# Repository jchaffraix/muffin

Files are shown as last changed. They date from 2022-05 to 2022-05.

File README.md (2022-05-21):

# muffin

A small mechanical keyboard for learning (and fun).

The goal is to build a small factor to learn how to build the PCB, soldering small components
and writing the firmware.

## Features

* USB-C connector.
* 5 keys, using Cherry MX or Kailh choc switches, including a 2U with a stabilizer.
* 1 rotary encoder.
* ATmega16 based.
* Mostly 805 SMT components.
* Include a programmer connector for ease of prototyping.
* A Muffin logo (because why not!?).

## PCB

The project relies on the [Keebio parts](https://github.com/keebio/Keebio-Parts.pretty) repository for the encoder and switch footprints.

To fetch the dependencies, run:

```
git submodule fetch
```

## Bill Of Materials

| Item | Package | Qty | Reference |
|---|---|-----|---|
| 10uF Capacitor | SMT 805 | 1 | |
| 1uF Capacitor | SMT 805 | 1 | |
| .1uF Capacitor | SMT 805 | 4 | |
| 22pF Capacitor | SMT 805 | 2 | |
| Diode | SMT 805 | 5 | Rated 5V |
| 5.5V Zener Diode | SMT 805 | 1 |  |
| LED Red | SMT 805 | 1 | |
| LED Blue | SMT 805 | 1 | |
| LED Green | SMT 805 | 1 | |
| 10k resistor | SMT 805 | 1 | |
| 5.1k resistor | SMT 805 | 2 | |
| 330 resistor | SMT 805 | 4 | |
| 22 resistor | SMT 805 | 2 | |
| USB ESD protection | SOT-143 | 1 |  Used D1213A-02SR-7|
| USB C receptable (female) | | 1 | Used HRO-TYPE-C-31-M-12 |
| AVR-ISP-6 connector | | 1 | |
| RotaryEncoder Switch | | 1 | Used Alps EC11 |
| Cherry or Kailh choc Switches | | 5 | |
| Switch stabilizer for 2U | | 1 | |
| ATmega16U4-M | QFN-44 | 1 | ATmega32U4 should work too|
| 16MHz crystal | | 1 | Used 3155-16M20P2/49US-ND |
| Reset switch | | 1 | Used MJTP1117 |
| Optional programming Switch | SMT 254 | 1 | Used 2223-DS04-254-2-01BK-SMT-ND |

Note: The crystal and the 2pF capacitors can be omitted if you use the internal clock (which requires programming some bits on the ATmega16).

## Compiling and flashing

Coming soon.

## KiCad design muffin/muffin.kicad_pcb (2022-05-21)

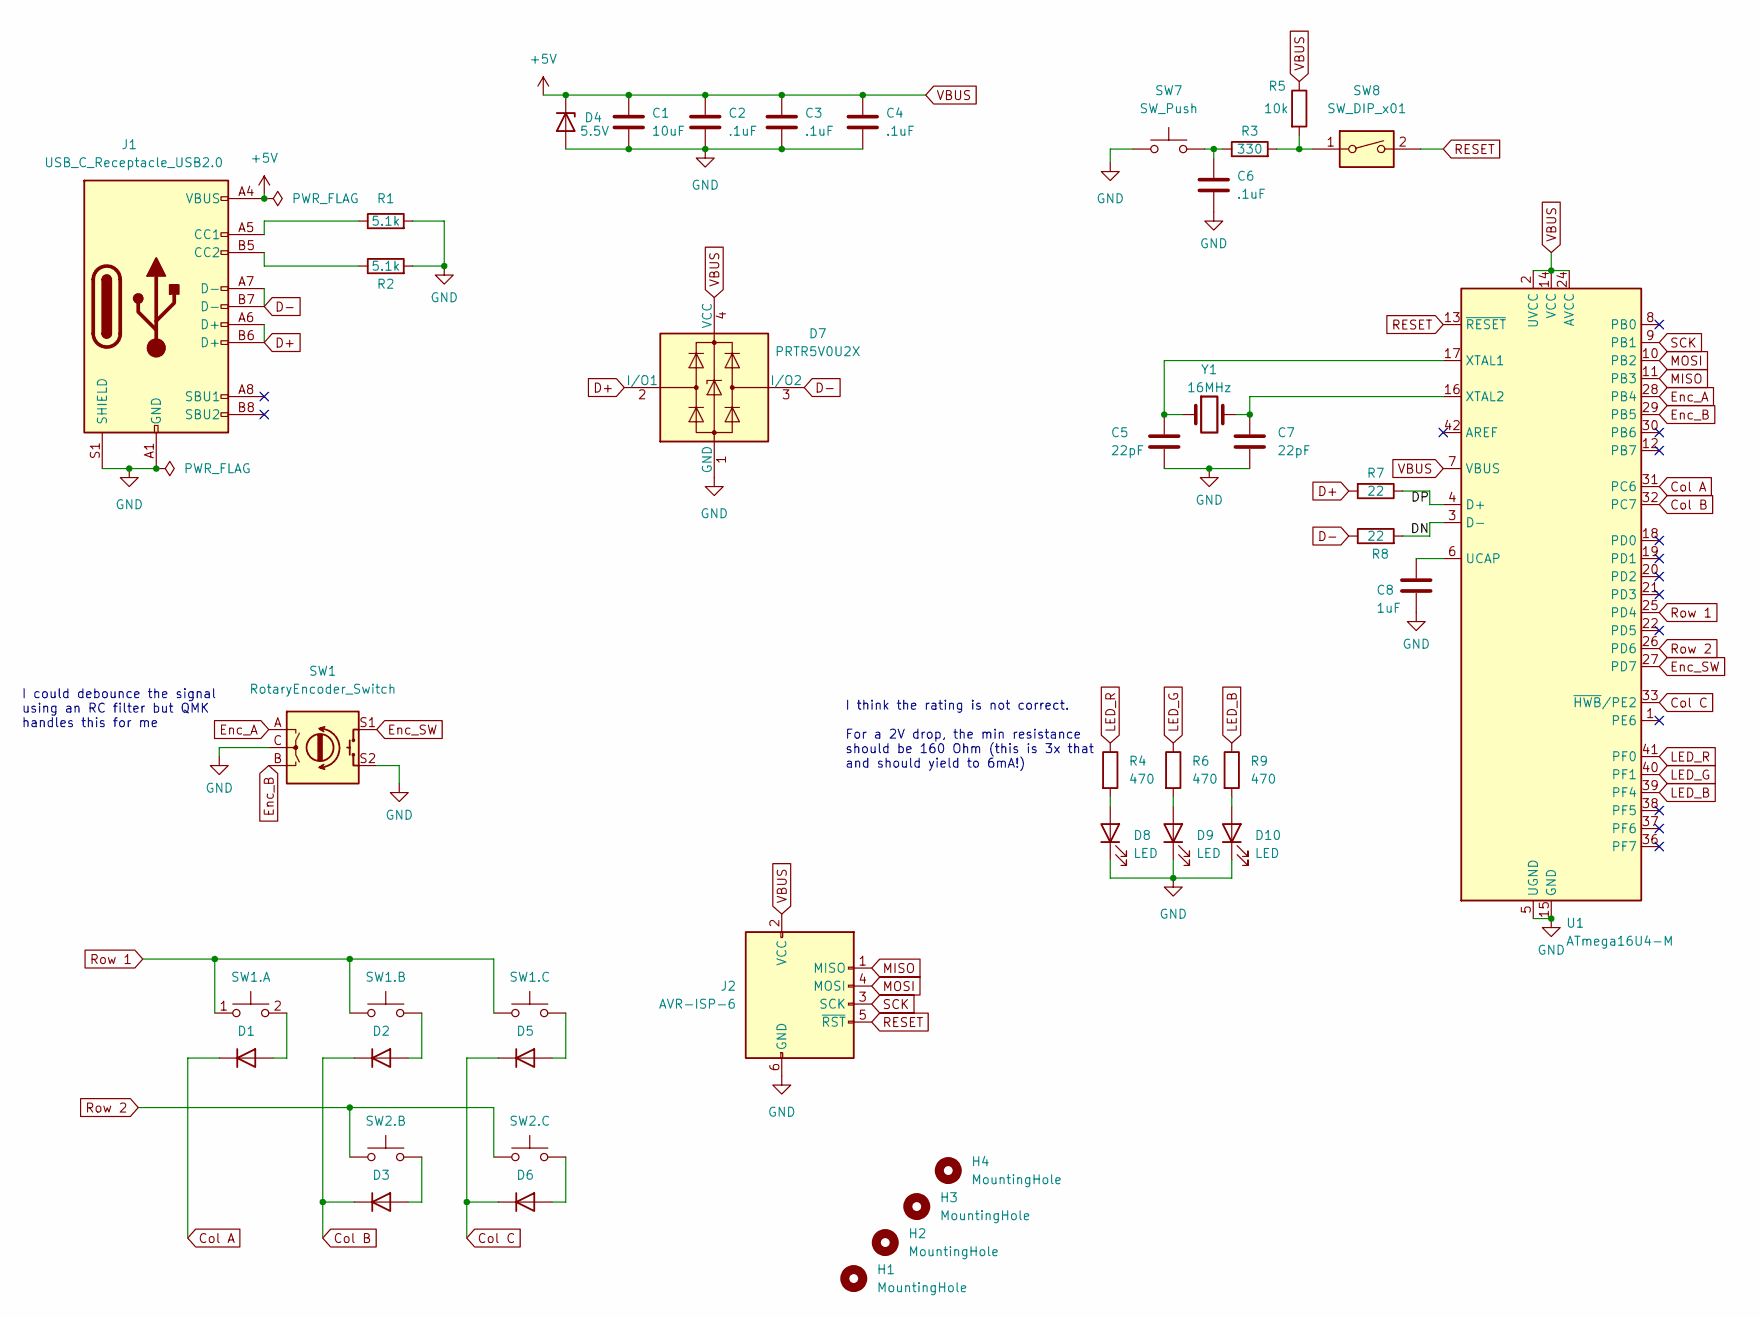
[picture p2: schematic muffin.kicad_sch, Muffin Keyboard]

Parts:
C1: 10uF; C_0805_2012Metric_Pad1.18x1.45mm_HandSolder
C2, C3, C4, C6: .1uF; C_0805_2012Metric_Pad1.18x1.45mm_HandSolder
C5, C7: 22pF; C_0805_2012Metric_Pad1.18x1.45mm_HandSolder
C8: 1uF; C_0805_2012Metric_Pad1.18x1.45mm_HandSolder
D1, D2, D3, D5, D6: D; D_0805_2012Metric_Pad1.15x1.40mm_HandSolder
D4: 5.5V; D_0805_2012Metric_Pad1.15x1.40mm_HandSolder
D7: PRTR5V0U2X; SOT-143
D8, D9, D10: LED; D_0805_2012Metric_Pad1.15x1.40mm_HandSolder
H1, H2, H3, H4: MountingHole; MountingHole_3.2mm_M3
J1: USB_C_Receptacle_USB2.0; HRO-TYPE-C-31-M-12-Assembly
J2: AVR-ISP-6; IDC-Header_2x03_P2.54mm_Horizontal
R1, R2: 5.1k; R_0805_2012Metric_Pad1.20x1.40mm_HandSolder
R3: 330; R_0805_2012Metric_Pad1.20x1.40mm_HandSolder
R4, R6, R9: 470; R_0805_2012Metric_Pad1.20x1.40mm_HandSolder
R5: 10k; R_0805_2012Metric_Pad1.20x1.40mm_HandSolder
R7, R8: 22; R_0805_2012Metric_Pad1.20x1.40mm_HandSolder
SW1: RotaryEncoder_Switch; RotaryEncoder_EC11
SW2: SW1.A; MX-Alps-Choc-2U
SW3: SW1.B; MX-Alps-Choc-1U-NoLED
SW4: SW2.B; MX-Alps-Choc-1U-NoLED
SW5: SW1.C; MX-Alps-Choc-1U-NoLED
SW6: SW2.C; MX-Alps-Choc-1U-NoLED
SW7: SW_Push; SW_Tactile_SPST_Angled_MJTP1117
SW8: SW_DIP_x01; DS04-254-SMT
U1: ATmega16U4-M; QFN-44-1EP_7x7mm_P0.5mm_EP5.2x5.2mm
Y1: 16MHz; Crystal_HC49-U_Vertical

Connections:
/DN: R8.2, U1.3 (D-)
/DP: R7.1, U1.4 (D+)
Col A: D1.1 (K), U1.31 (PC6)
Col B: D2.1 (K), D3.1 (K), U1.32 (PC7)
Col C: D5.1 (K), D6.1 (K), U1.33 (~HWB/PE2)
D+: D7.2 (I/O1), J1.A6 (D+), J1.B6 (D+), R7.2
D-: D7.3 (I/O2), J1.A7 (D-), J1.B7 (D-), R8.1
Enc_A: SW1.A, U1.28 (PB4)
Enc_B: SW1.B, U1.29 (PB5)
Enc_SW: SW1.S1, U1.27 (PD7)
GND: C1.2, C2.2, C3.2, C4.2, C5.2, C6.2, C7.2, C8.2, D4.2 (A), D7.1 (GND), D8.1 (K), D9.1 (K), D10.1 (K), J1.A1 (GND), J1.A12 (GND), J1.B1 (GND), J1.B12 (GND), J1.S1 (SHIELD), J2.6 (GND), R1.2, R2.2, SW1.C, SW1.S2, SW7.1, U1.5 (UGND), U1.15 (GND), U1.23 (GND), U1.35 (GND), U1.43 (GND), U1.45 (GND)
LED_B: R9.1, U1.39 (PF4)
LED_G: R6.1, U1.40 (PF1)
LED_R: R4.1, U1.41 (PF0)
MISO: J2.1 (MISO), U1.11 (PB3)
MOSI: J2.4 (MOSI), U1.10 (PB2)
unnamed: C5.1, U1.17 (XTAL1), Y1.1
unnamed: C6.1, R3.1, SW7.2
unnamed: C7.1, U1.16 (XTAL2), Y1.2
unnamed: C8.1, U1.6 (UCAP)
unnamed: D1.2 (A), SW2.2
unnamed: D2.2 (A), SW3.1
unnamed: D3.2 (A), SW4.1
unnamed: D5.2 (A), SW5.1
unnamed: D6.2 (A), SW6.1
unnamed: D8.2 (A), R4.2
unnamed: D9.2 (A), R6.2
unnamed: D10.2 (A), R9.2
unnamed: J1.A5 (CC1), R1.1
unnamed: J1.B5 (CC2), R2.1
unnamed: R3.2, R5.2, SW8.1
RESET: J2.5 (~RST), SW8.2, U1.13 (~RESET)
Row 1: SW2.1, SW3.2, SW5.2, U1.25 (PD4)
Row 2: SW4.2, SW6.2, U1.26 (PD6)
SCK: J2.3 (SCK), U1.9 (PB1)
VBUS: C1.1, C2.1, C3.1, C4.1, D4.1 (K), D7.4 (VCC), J1.A4 (VBUS), J1.A9 (VBUS), J1.B4 (VBUS), J1.B9 (VBUS), J2.2 (VCC), R5.1, U1.2 (UVCC), U1.7 (VBUS), U1.14 (VCC), U1.24 (AVCC), U1.34 (VCC), U1.44 (AVCC)

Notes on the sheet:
I could debounce the signal using an RC filter but QMK handles this for me
I think the rating is not correct. For a 2V drop, the min resistance should be 160 Ohm (this is 3x that and should yield to 6mA!)

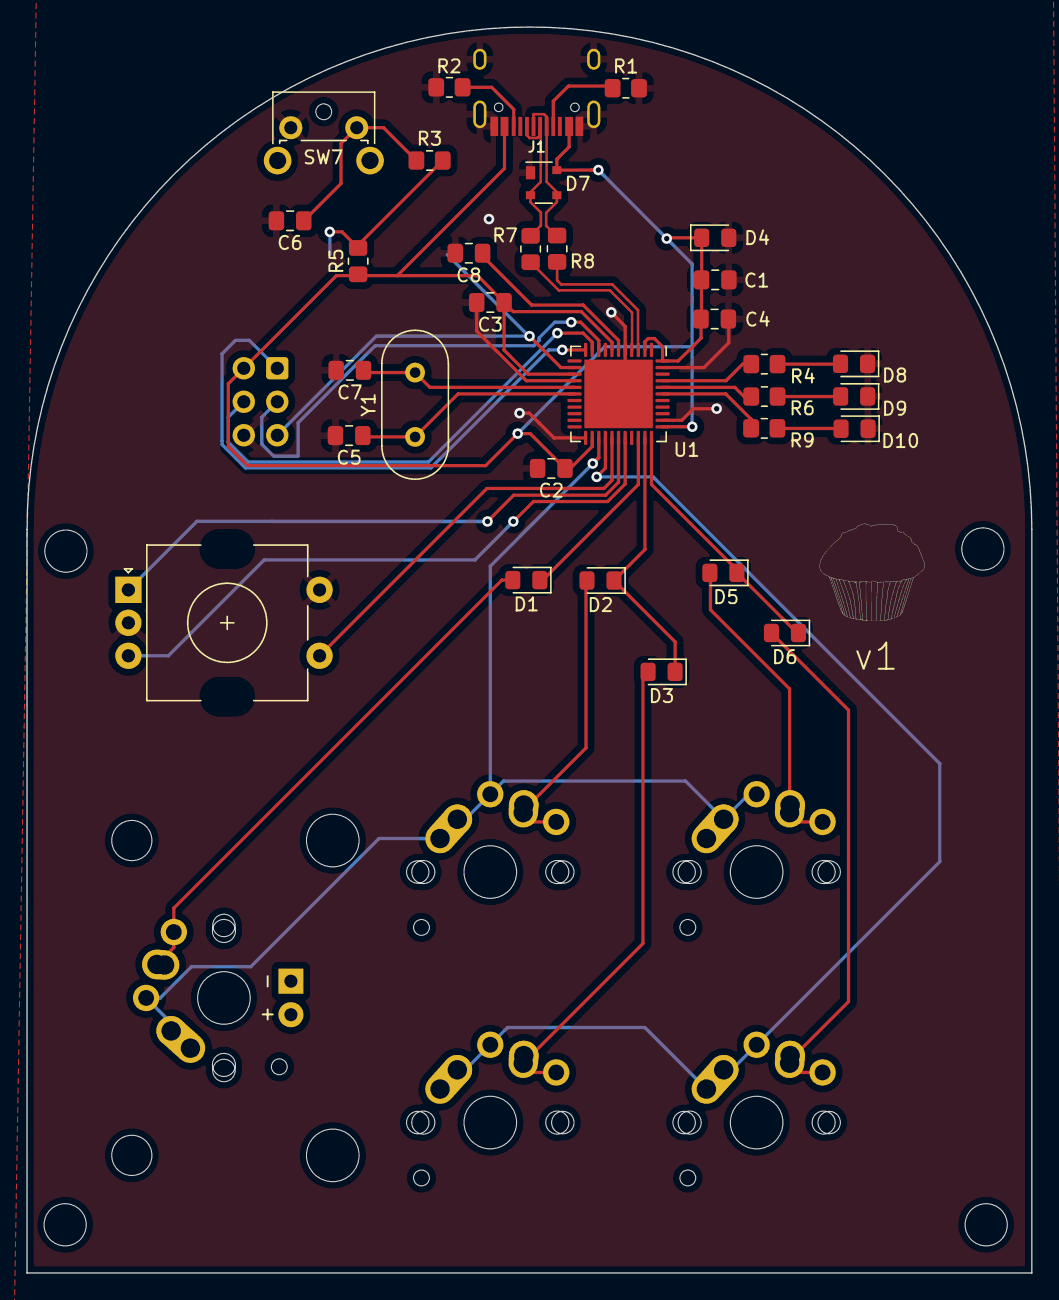
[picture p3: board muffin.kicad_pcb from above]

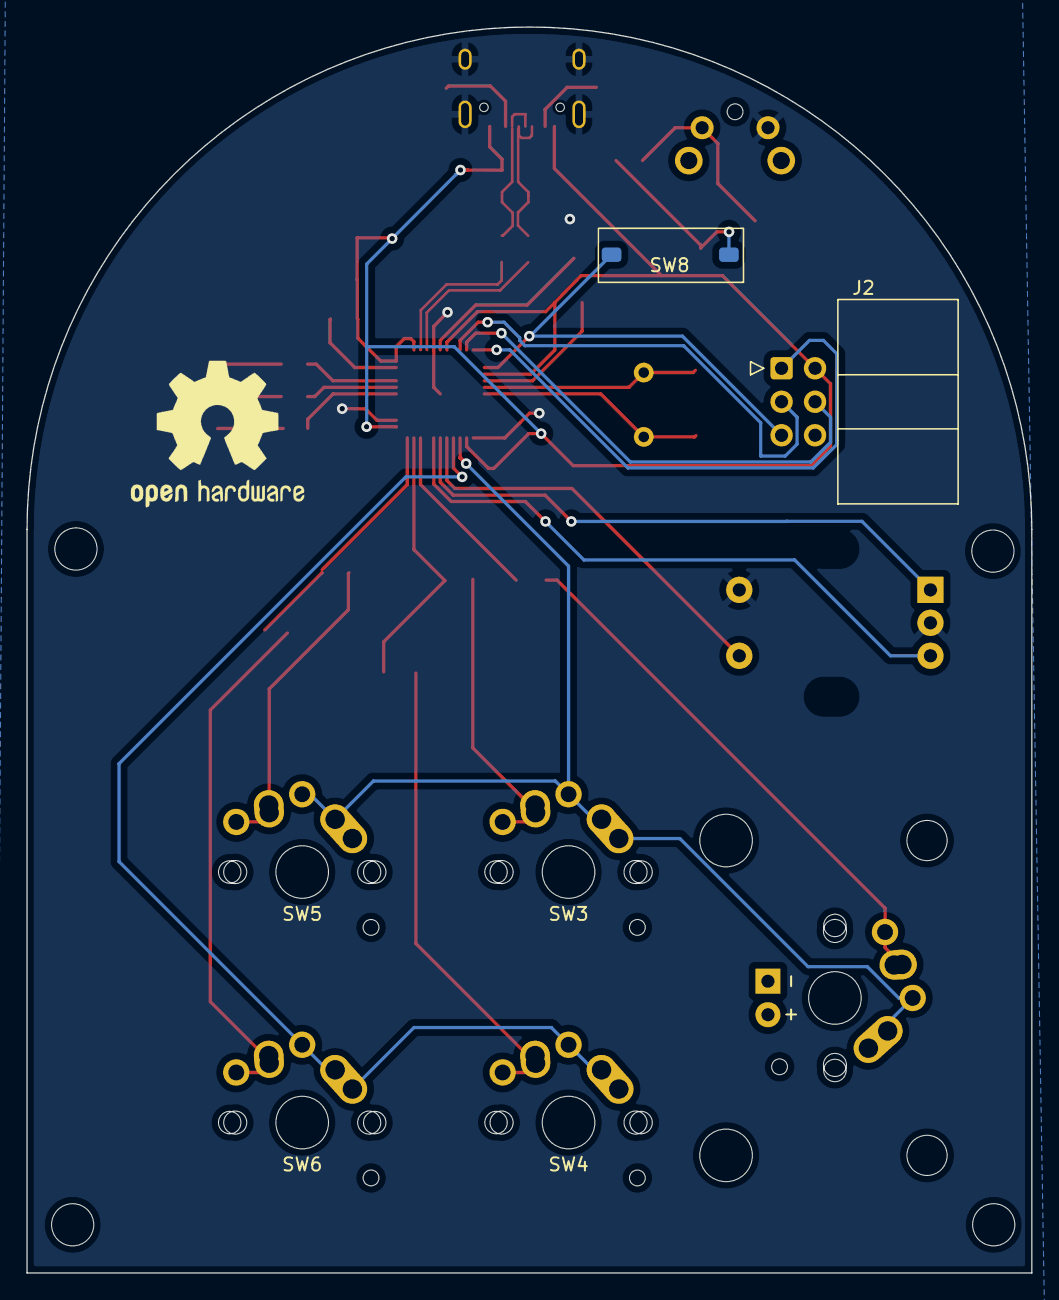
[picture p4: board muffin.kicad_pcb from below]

Board: 2 copper layers, 76.2 x 94.5 mm, 43 parts (2 on the bottom side), 36 nets.

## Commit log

2022-05-21 Add plans for v1
    The schematics is done and the PCB should
    be functional.
    I may decide to rework the diode layout.
    [muffin.kicad_pcb, muffin.kicad_sch]
2022-05-21 Update switches footprint
    I was using the LED version of the footprint for all 1U switches.
    I didn't change the 2U footprint as that would have required
    updating the Keebio library.
    [muffin.kicad_pcb, muffin.kicad_sch]
2022-05-21 Fill the README
    Also corrected the resistor for the LEDs to simplify the BOM.
    The programming section will be filled when I get the PCB
    and solder the components.
    [muffin.kicad_sch]
2022-05-22 Add the generated gerber files
    This allows checking the final output for the
    V1.
    While I included the schematics for the V1 that
    was used to generate the PCB.
    [muffin-B_Cu.gbr, muffin-B_Mask.gbr, muffin-B_Paste.gbr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]
